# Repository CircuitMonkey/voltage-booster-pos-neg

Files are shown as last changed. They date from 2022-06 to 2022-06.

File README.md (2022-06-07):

# voltage-booster-pos-neg
Low voltage to +/-9V voltage booster circuit using MIC2145.

## About this Circuit
Experimental PCB that boosts nominal 3.7V to 9VDC while also adding
a -9VDC rail.  I needed both +9 and -9 for an analog sythesizer experiment
but my power supply design got a little complicated and expensive using
Pololu boost modules.  Once I built my synth circuit, I was able to characterize
my power needs (about 200mA at 9V and much less at -9V).

Based on this application note from Texas Instruments:
https://www.ti.com/lit/an/slvaej3/slvaej3.pdf

Will it work?

## Images
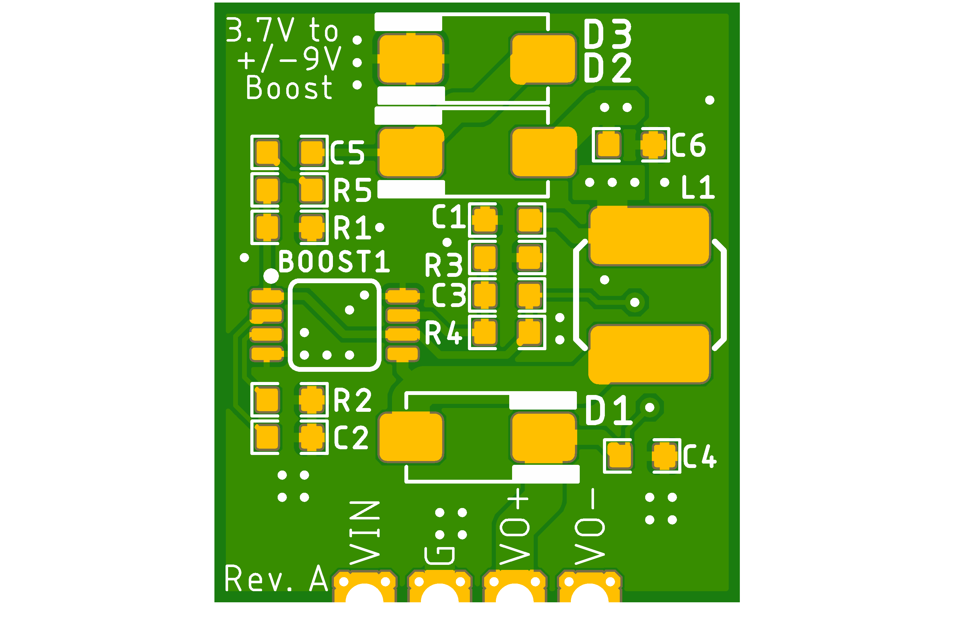
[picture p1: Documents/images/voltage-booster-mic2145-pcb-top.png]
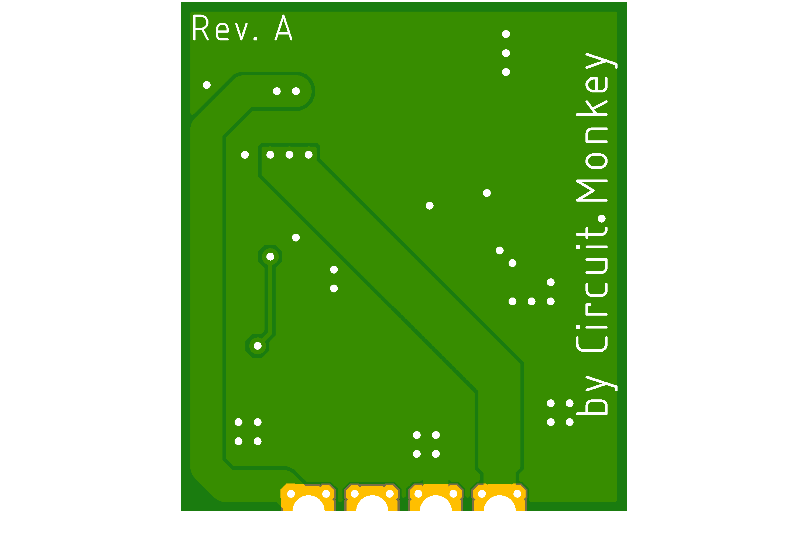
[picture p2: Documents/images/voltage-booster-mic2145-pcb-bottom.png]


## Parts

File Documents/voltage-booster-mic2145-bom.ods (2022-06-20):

Voltage Booster – MIC2145 – 3.7V in to +9 and -9V
Rev.A
Part | Value | Package | Description | COST01 | COST10 | COST100 | MFR | MPN | VALUE
BOOST1 | MIC2145 | MSOP8-0.65 | Micrel 2145 Boost Converter | 2.75 | 2.71 | 2.7 | Micrel | MIC2145YMM | MIC2145
C1 | 10uF/6.3V | 0603-CAP | Capacitor | 0.12 | 0.09 | 0.05
C2 | 0.01uF | 0603-CAP | Capacitor | 0.12 | 0.09 | 0.05
C3 | 100pF | 0603-CAP | Capacitor | 0.12 | 0.09 | 0.05
C4 | 10uF/16V | 0603-CAP | Capacitor | 0.12 | 0.09 | 0.05
C5 | 2.2uF | 0603-CAP | Capacitor | 0.12 | 0.09 | 0.05
C6 | 2.2uF | 0603-CAP | Capacitor | 0.12 | 0.09 | 0.05
D1 | B140 | SMA | Schottky Diodes | 0.38 | 0.28 | 0.18 | Vishay/Various | B140 | B140
D2 | B140 | SMA | Schottky Diodes | 0.38 | 0.28 | 0.18 | Vishay/Various | B140 | B140
D3 | B140 | SMA | Schottky Diodes | 0.38 | 0.28 | 0.18 | Vishay/Various | B140 | B140
L1 | 4.7uH | IND-SRN5040 | Inductor |  |  |  | Bourns | SRN5040
R1 | 100K | 0603-RES | Resistor | 0.1 | 0.05 | 0.02
R2 | 200 | 0603-RES | Resistor | 0.1 | 0.05 | 0.02
R3 | 136K | 0603-RES | Resistor | 0.1 | 0.05 | 0.02
R4 | 1M | 0603-RES | Resistor | 0.1 | 0.05 | 0.02
R5 | 1 ohm | 0603-RES | Resistor | 0.1 | 0.05 | 0.02

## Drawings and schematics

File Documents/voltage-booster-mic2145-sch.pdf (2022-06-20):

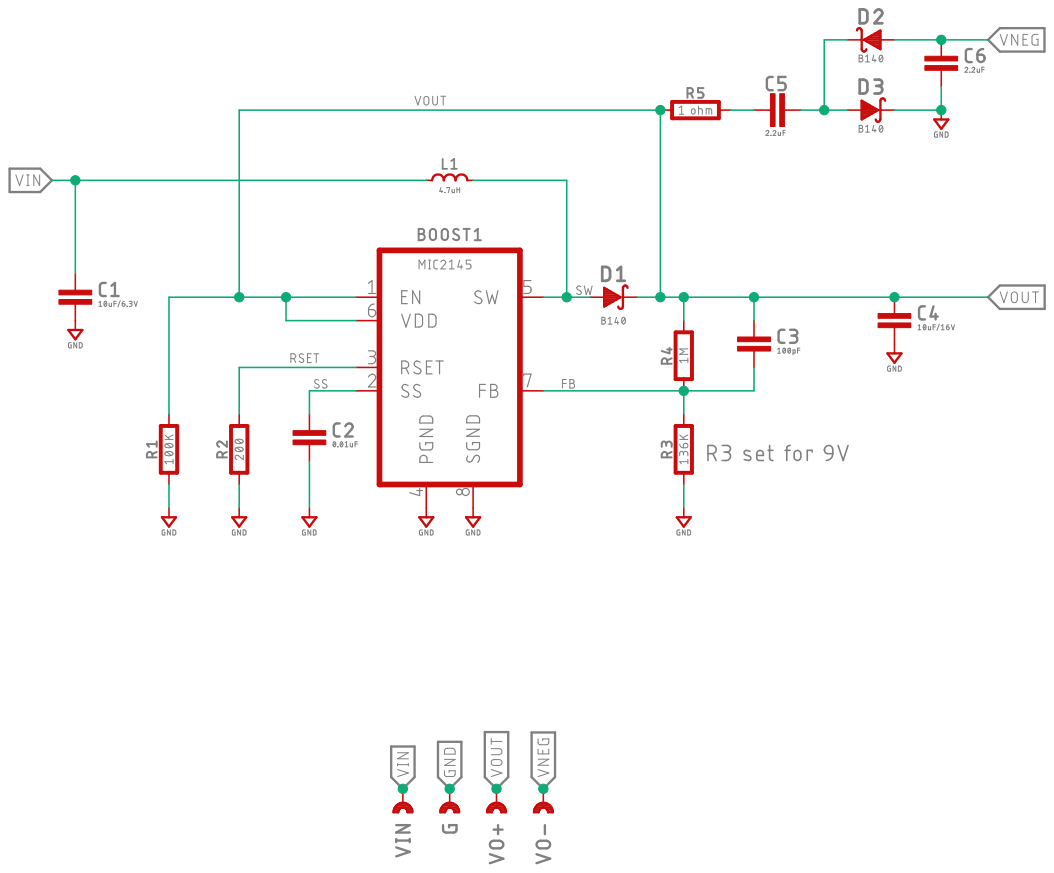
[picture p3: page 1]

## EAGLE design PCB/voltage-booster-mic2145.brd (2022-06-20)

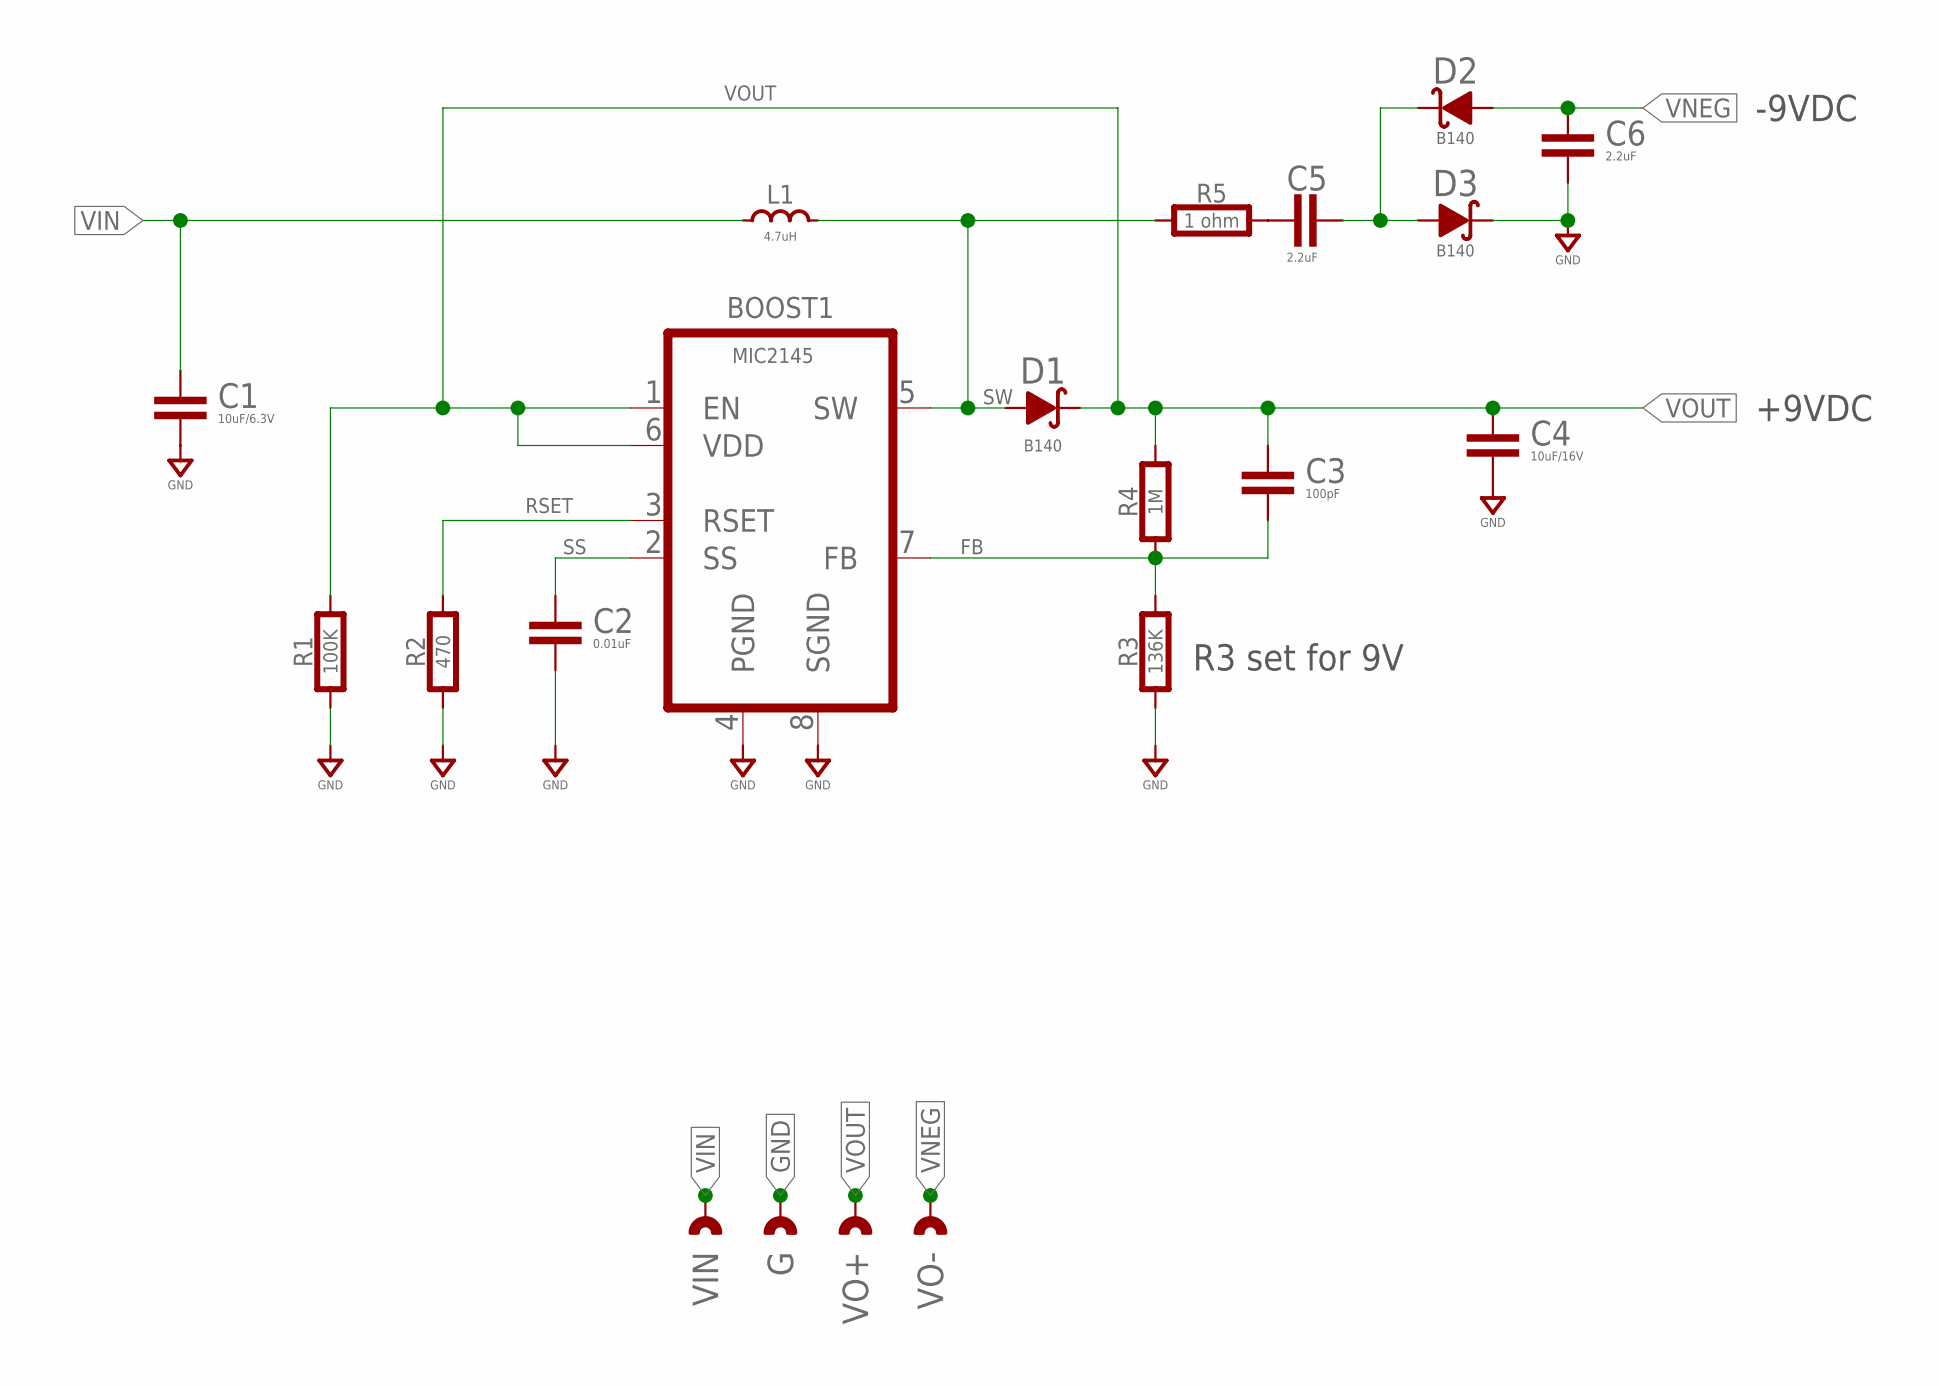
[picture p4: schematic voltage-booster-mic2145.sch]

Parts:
BOOST1: MIC2145; MSOP8-0.65
C1: 10uF/6.3V; 0603-CAP
C2: 0.01uF; 0603-CAP
C3: 100pF; 0603-CAP
C4: 10uF/16V; 0603-CAP
C5, C6: 2.2uF; 0603-CAP
D1, D2, D3: B140; SMA
G: CAST-01X12.54MM; CAST01-2.54MM
L1: 4.7uH; IND-SRN5040
R1: 100K; 0603-RES
R2: 470; 0603-RES
R3: 136K; 0603-RES
R4: 1M; 0603-RES
R5: 1 ohm; 0603-RES
VIN: CAST-01X12.54MM; CAST01-2.54MM
VO+: CAST-01X12.54MM; CAST01-2.54MM
VO-: CAST-01X12.54MM; CAST01-2.54MM

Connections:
FB: BOOST1.7 (FB), C3.2, R3.2, R4.1
GND: BOOST1.4 (PGND), BOOST1.8 (SGND), C1.2, C2.2, C4.2, C6.2, D3.K, G.1, R1.1, R2.1, R3.1
unnamed: C5.1, R5.2
unnamed: C5.2, D2.K, D3.A
RSET: BOOST1.3 (RSET), R2.2
SS: BOOST1.2 (SS), C2.1
SW: BOOST1.5 (SW), D1.A, L1.1, R5.1
VIN: C1.1, L1.2, VIN.1
VNEG: C6.1, D2.A, VO-.1
VOUT: BOOST1.1 (EN), BOOST1.6 (VDD), C3.1, C4.1, D1.K, R1.2, R4.2, VO+.1

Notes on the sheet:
R3 set for 9V
-9VDC
+9VDC

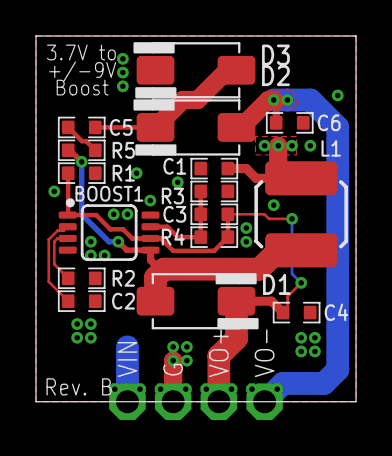
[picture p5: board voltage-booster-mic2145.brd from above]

Board: 2 copper layers, 17.8 x 20.3 mm, 20 parts (0 on the bottom side), 10 nets.

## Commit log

2022-06-07 Rev. A
    [voltage-booster-mic2145.brd, voltage-booster-mic2145.sch]
2022-06-07 Add PCB images
2022-06-20 Ad/update component values.
    [voltage-booster-mic2145.brd, voltage-booster-mic2145.sch]
2022-06-20 Datasheet, create BOM, document schematic
    [voltage-booster-mic2145-bom.ods]
2022-06-20 Fix error where neg-volt section on wrong signal.
    Bumped rev to B
    [voltage-booster-mic2145.brd, voltage-booster-mic2145.sch]
2022-08-06 Added schematic notes.
    [voltage-booster-mic2145.sch]
